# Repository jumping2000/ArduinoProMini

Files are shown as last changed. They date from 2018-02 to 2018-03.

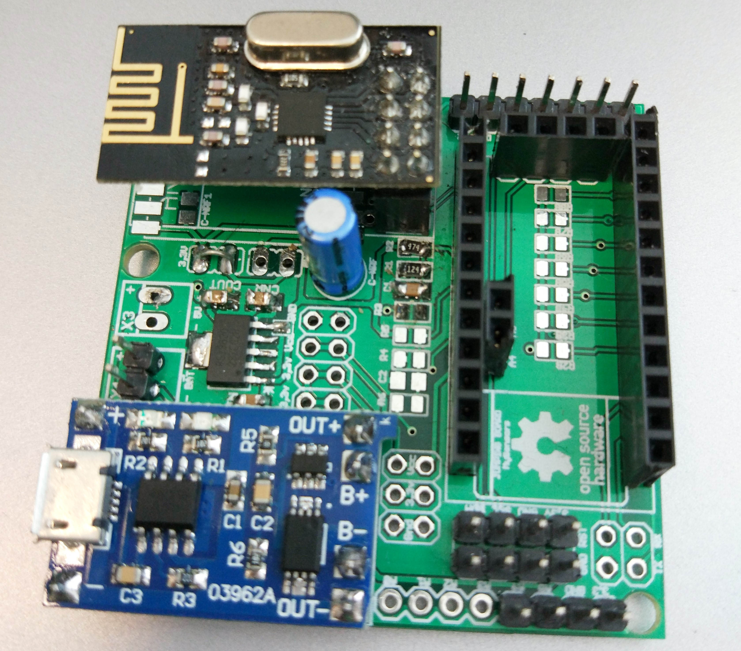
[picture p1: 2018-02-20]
JMP_PROMINI-v21/IMG/IMG_20170829_105242 (2).jpg

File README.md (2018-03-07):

# JMP ArduinoProMini Multisensor Board
Arduino Pro Mini board for MySensors,the board is designed for multiple sensors.

**Supply**

1. LiOn battery
2. 5V
3. 2xAA battery

**Boards features:**
1. LiOn battery support
2. NRF24L01+ support
3. RFM69 support
4. ATSHA204A signing chip
5. AT25DF512C EEPROM chip
6. designed for multiple sensors (multiple I2C sensors, analog and digital sensors)
7. Accept Arduino Pro Mini 3.3V and 5V

------------------------------------------------
**LiOn Battery --> 3.3V** - Arduino Pro Mini 8Mhz and 3.3V
1. Weld the  regulator (IC1) and the other capacitor (Cin,Cout, C-NRF, etc)
2. short-circuit the 3.3v jumper
3. weld the C1, R1, R2 parts (voltage divider circuit)
4. use a TP4056 module and attach the LiOn battery on X1 input

**5V** - Arduino Pro Mini 16Mhz and 5V
1. Weld the  regulator (IC1) and the other capacitor (Cin,Cout, C-NRF, etc)
2. short-circuit the 5v jumper and J2 pad
3. attach the the 5V supply on X3 input
4. the regulator gives 3.3v only to antenna

**AA Battery --> 3V** - Arduino Pro Mini 8Mhz and 3.3V
1. **DON'T weld** the  regulator (IC1) 
2. Weld the C-NRF capacitor 
3. short-circuit the 3.3v and 5V jumper, J2 pad
4. weld the C1, R1, R2 parts (voltage divider circuit)
5. attach the 2xAA battery on X3 input
------------------------------------------------

**Please note: the sensor images refer to previous version of the board**

**Disclaimer**
If you order or use this you agree to and understand that the author is not liable for any injury or damage howsoever caused and that you use this PCB at your own risk. This is DIY and the author has not made any professional test. This product has not been marked with any certification marks and can't be guaranteed to comply with any standards.

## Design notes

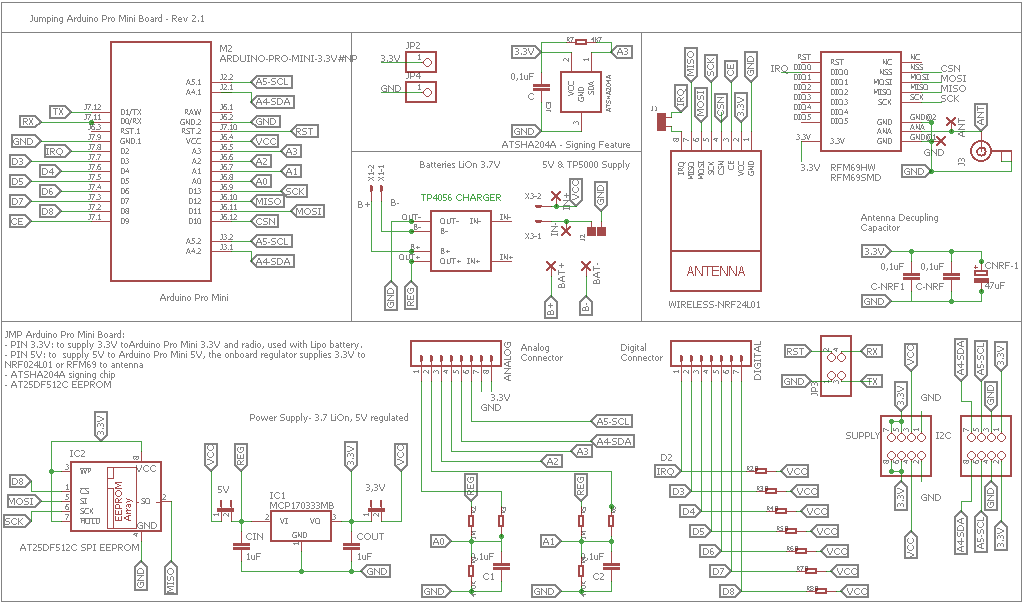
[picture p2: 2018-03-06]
JMP_PROMINI-v21/IMG/JMP_PROMINI-v21-SCH.png

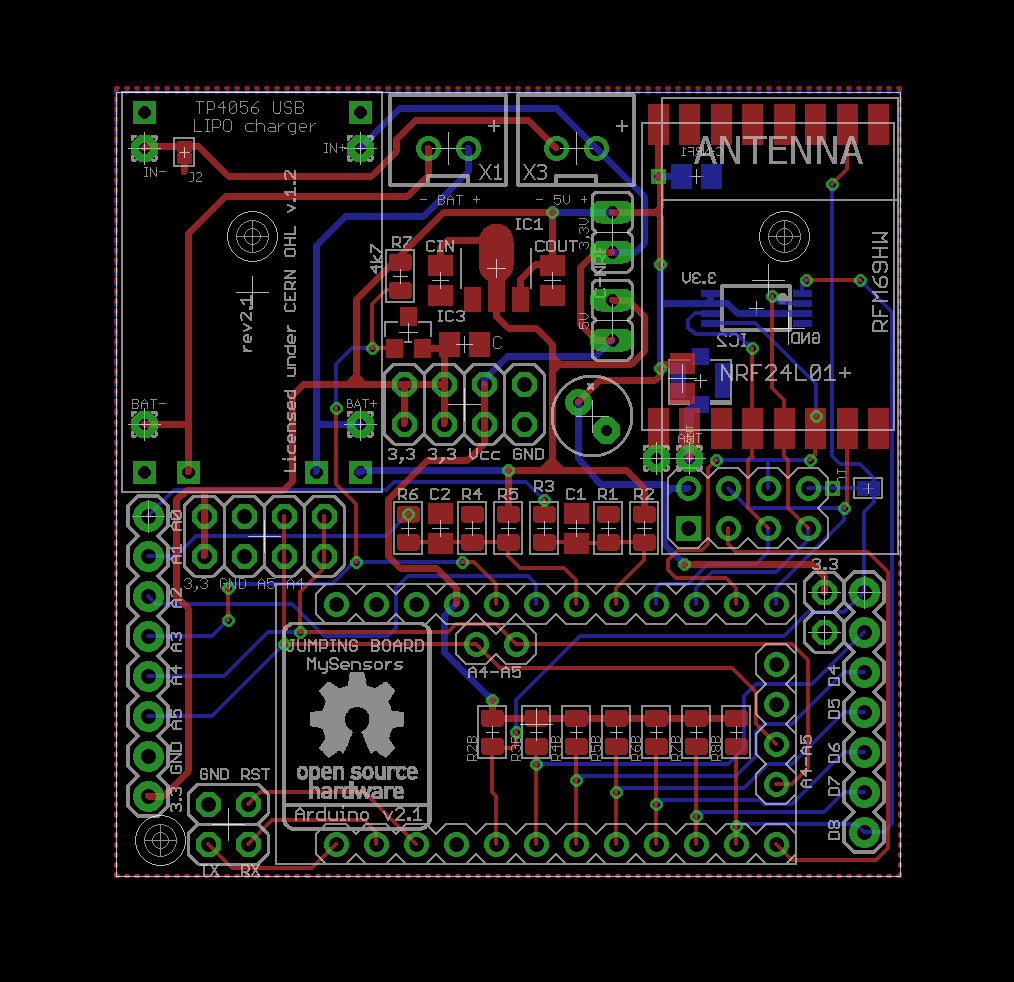
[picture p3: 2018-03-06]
JMP_PROMINI-v21/IMG/JMP_PROMINI-v21-BRD.png

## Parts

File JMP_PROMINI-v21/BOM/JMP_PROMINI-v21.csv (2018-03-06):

Qty | Value | Device | Package | Parts | Description | MF | MPN | OC_FARNELL | OC_NEWARK | PARTNO | PROD_ID | VALUE
6 |  | 1,6/0,8 | 1,6/0,8 | ANT, BAT+, BAT-, GND, IN+, IN- | THROUGH-HOLE PAD
2 |  | JP1E | JP1 | 3,3V, 5V | JUMPER
1 |  | M07 | 1X07 | DIGITAL | Header 7
1 |  | M08 | 1X08_ROUND | ANALOG | Header 8 |  |  |  |  |  | CONN-08437
2 |  | PAD-JUMPER-2P | 2P-SMD-1.78X1.27 | J1, J2 |  |  |  |  |  | DNP
2 |  | PINHD-1X1 | 1X01 | JP2, JP4 | PIN HEADER
1 |  | PINHD-2X2 | 2X02 | JP3 | PIN HEADER
2 |  | PINHD-2X4 | 2X04 | I2C, SUPPLY | PIN HEADER
9 |  | R-0805 | R0805 | R2B, R3, R3B, R4B, R5B, R6, R6B, R7B, R8B
5 | 0,1uF | C-EUC0805 | C0805 | C, C-NRF, C-NRF1, C1, C2 | CAPACITOR, European symbol
2 | 1M | R-0805 | R0805 | R2, R5
2 | 1uF | C-EUC0805 | C0805 | CIN, COUT | CAPACITOR, European symbol
2 | 470K | R-0805 | R0805 | R1, R4
1 | 47uF | CPOL-EUE2.5-5 | E2,5-5 | CNRF-1 | POLARIZED CAPACITOR, European symbol
1 | 4k7 | R-0805 | R0805 | R7
1 | ARDUINO-PRO-MINI-3.3V#NP | ARDUINO-PRO-MINI-3.3V#NP | ARDUINO-PRO-MINI#NP | M2 | Arduino Pro Mini without programming pads
1 | AT25DF512 | 25C040ST | TSSOP8 | IC2 | Serial EEPROM 4K/ 8K , SPI bus | MICROCHIP | 25C040T/SN | unknown | 30C5312
1 | ATSHA204A | ATSHA204A | SOT23 | IC3
2 | JST-XH-02-PIN-ROUND-PAD | JST-XH-02-PIN-ROUND-PAD | JST-XH-02-PACKAGE-ROUND-PAD | X1, X3 | JST XH Connector 2 Pin
1 | MCP170333MB | MCP170333MB | SOT89 | IC1 | 250 mA, 16V, Low Quiescent Current LDO Regulator
1 | RFM69SMD | RFM69SMD | 20X16SMD | RFM69HW | RFM69 module
1 | TP4056-MODULE | TP4056-MODULE | TP4056-LITHIUM-PROTECTED-MODULE | U$1
1 | U.FL | U.FL | U.FL | J3 | SMD antenna connector- WRL-09144 |  |  |  |  |  | CONN-09193 | U.FL
1 | WIRELESS-NRF24L01 | WIRELESS-NRF24L01 | WIRELESS-NRF24L01 | NRF24L01+ | 2.4 GHz Wireless Module based on NRF24L01 chip

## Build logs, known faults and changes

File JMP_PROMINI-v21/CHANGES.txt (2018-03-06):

Modifications made by Licensee (see section 3.4.b in )

Rev 1
Prototype version, not published

Rev 2
Board Arduino PRO Mini with NRF24L01 and RFM69 antenna, TP4056 LiOn charger circuit, MCP1700 Voltage regulator, many pin to connect sensors.

Rev 2.1
Added ATSHA204A chip for signing, added EEPROM chip AT25D512, added UF.L antenna socket
